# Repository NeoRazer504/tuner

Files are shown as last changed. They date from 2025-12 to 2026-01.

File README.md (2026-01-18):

# Tuner
This is a chromatic instrument tuner I made for myself because I'm a band nerd and I need a better tuner so instead of buying one, I thought it would be better to make one :). (This is my first custom project so hope it works🙏).
## Features
- Powered by a Xiao nRF52840
- Built in microphone and a jack so you can choose to use a external mic instead
- 2.42" OLED
- 3 LEDs to indicate if you're flat, sharp, or in tune
- 2 buttons to adjust hertz
- 500 mAh battery
## Gallery





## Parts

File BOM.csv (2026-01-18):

Item | Description | URL | Cost
Xiao nRF52840 | Microcontroller | https://www.digikey.com/en/products/detail/seeed-technology-co-ltd/102010448/16652893 | $9.99
3 LEDs | Pitch indicators | https://www.digikey.com/en/products/detail/american-opto-plus-led/L513SRD-C/13556881 | Already Have
3 220Ω Resistors | Resistors for LEDs | https://www.digikey.com/en/products/detail/stackpole-electronics-inc/CFM14JT220R/1742139 | Already Have
2 Buttons | Hertz controllers | https://www.digikey.com/en/products/detail/same-sky-formerly-cui-devices-/TS02-66-43-BK-100-LCR-D/15634359 | Already Have
2.42″ 2.42 inch OLED Display Module | OLED display | https://www.esp32s.com/product/2-42-2-42-inch-oled-display-module-128x64-lcd-hd-screen-module-ssd1309-7-pin-spi-iic-i2c-serial-interface-for-arduino-uno-r3 | $9.05
Adafruit I2S MEMS SPH0645LM4H | Microphone | https://www.adafruit.com/product/3421 | $6.95
Adafruit LiIon/LiPoly Backpack Add-On for Pro Trinket/ItsyBitsy | Battery charging add-on | https://www.adafruit.com/product/2124 | $4.95
Lithium Ion Polymer Battery - 3.7v 500mAh | Battery powering the tuner | https://www.digikey.com/en/products/detail/adafruit-industries-llc/1578/5054539 | $7.95
RN112BPC | 1/4 inch Jack for external microphones | https://www.digikey.com/en/products/detail/switchcraft-inc/RN112BPC/109625 | $5.67
09816 | Adapter and signal modifier for jack and microcontroller | https://www.digikey.com/en/products/detail/sparkfun-electronics/09816/5762428 | $7.25
EG1201A | Switch to turn on and off | https://www.digikey.com/en/products/detail/e-switch/EG1201A/101723 | $0.84
2 RM2X8MM 2701 | Screws for switch | https://www.digikey.com/en/products/detail/apm-hexseal/RM2X8MM-2701/612919? | $1.48
2 04M020040HN | Nuts for switch | https://www.digikey.com/en/products/detail/essentra-components/04M020040HN/9677098 | $0.30
4 6007 | Screws to attach top and bottom part of the case | https://www.digikey.com/en/products/detail/serpac/6007/307639 | $1.56
3D prints
PCB |  | https://jlcpcb.com/ | $2.00
Total cost |  |  | $67.59 + 21.37 for shipping = 79.16

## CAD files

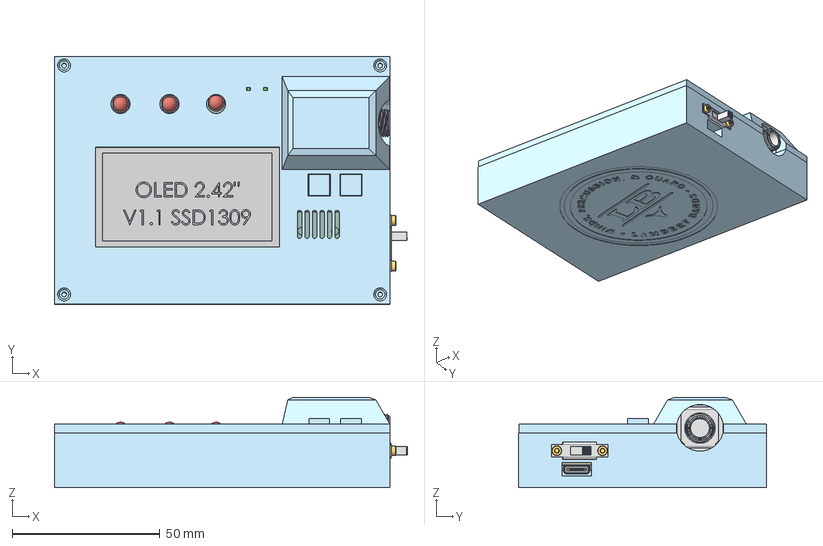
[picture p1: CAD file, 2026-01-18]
cad/assembly.step
119.5 x 84.0 x 30.6 mm
BOSS-EXTRUDE14_5_
_0805MP x 3
JSTPH2 x 5
BOSS-EXTRUDE14_7_
Silkscreen x 13
CAP x 6
0805-NO x 5
PCB (1) x 16
CHIPLED_0805_NOOUTLINE x 2
BOSS-EXTRUDE14_9_
LED x 4
500mAh battery v1
90695A025_Steel Thin Hex Nut x 2
4 PIN HEADER v2 x 2
R_Axial_DIN0207_L6.3mm_D2.5mm_P7.62mm_Horizontal x 3
BOSS-EXTRUDE14_3_
BOSS-EXTRUDE7_7_
BOSS-EXTRUDE14_4_
LED_D5.0mm x 3
CAP 3 x 3
BOSS-EXTRUDE14_10_
BOSS-EXTRUDE7_9_
Pins x 4
USR
SW_PUSH_6mm x 2
BOSS-EXTRUDE14_1_
BOSS-EXTRUDE7_5_
MIRROR2
3 PIN HEADER blk v1
Adafruit I2S Mic SPK0415HM4H_PCB
BOSS-EXTRUDE7_3_
P:\E-Switch Secure\3D_MODELS_STP_FORMAT\EG1201A.st p
BOSS-EXTRUDE7_1_
BOSS-EXTRUDE7_4_
96817A212_Thread-Forming Screws for Thin Plastic x 2
SparkFun_OpAmp_Breakout-LMV358_PCB
BOSS-EXTRUDE14_11_
XIAO-nRF52840 v15 v2
BOSS-EXTRUDE7_6_
Shield
RN112BPC
Board
BOSS-EXTRUDE14_2_
ANT1 x 3
BOSS-EXTRUDE7_2_
BOSS-EXTRUDE14_12_
SOT23-5
CUT-EXTRUDE5
6 pin header
BOSS-EXTRUDE14_6_
tuner_PCB
OLED 2.42 V1.1 SSD1309
BOSS-EXTRUDE14_8_
BOSS-EXTRUDE7_8_

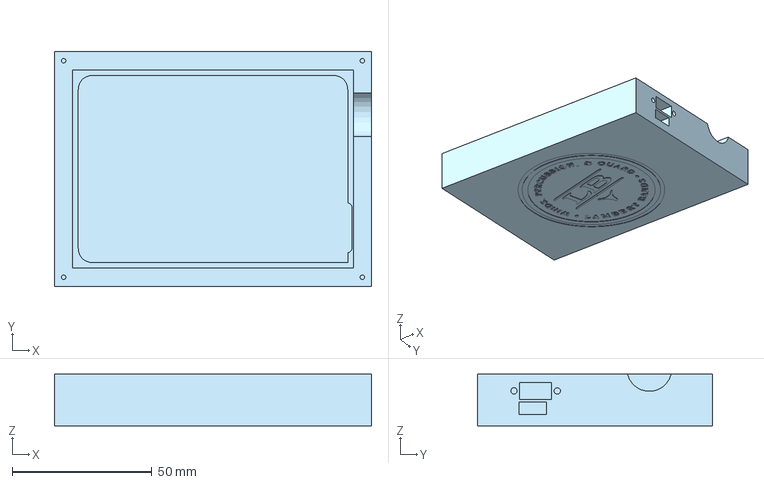
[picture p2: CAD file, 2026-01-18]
cad/Bottom Case.step
113.5 x 84.0 x 18.5 mm

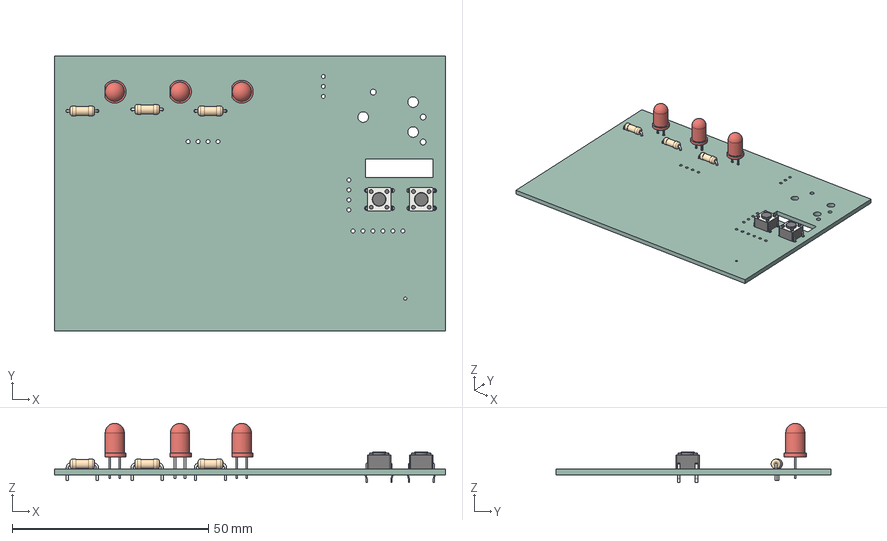
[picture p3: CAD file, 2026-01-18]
pcb/tuner.step
99.5 x 70.0 x 15.1 mm
LED_D5.0mm x 3
R_Axial_DIN0207_L6.3mm_D2.5mm_P7.62mm_Horizontal x 3
SW_PUSH_6mm x 2
tuner_PCB

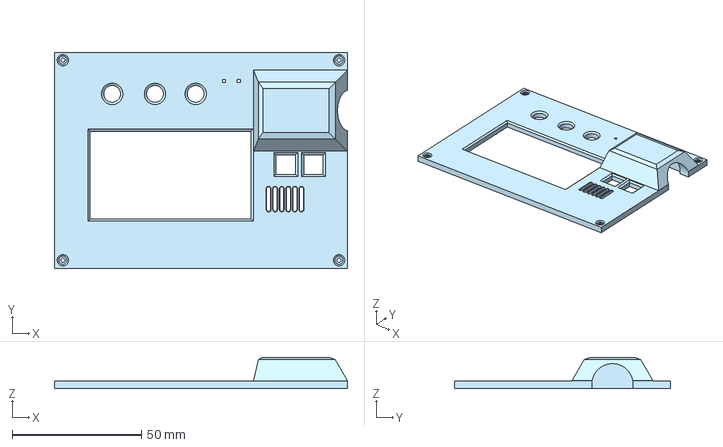
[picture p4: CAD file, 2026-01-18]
cad/Top Plate.step
113.5 x 83.8 x 12.1 mm

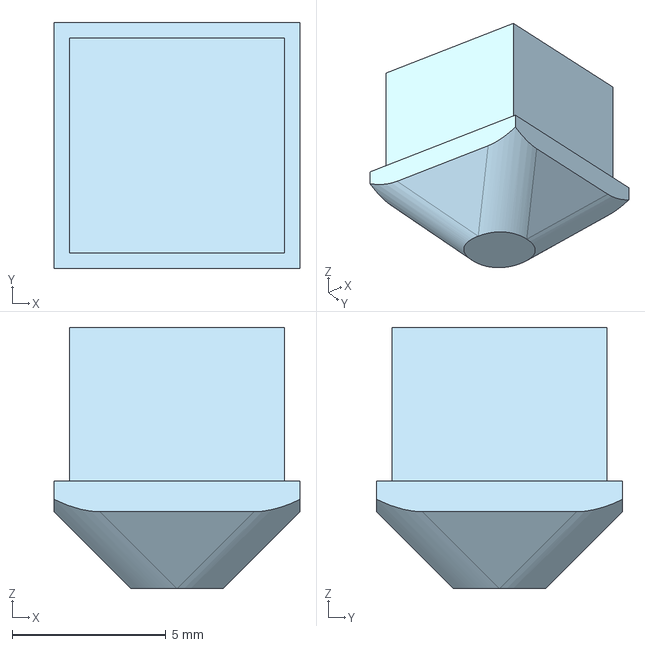
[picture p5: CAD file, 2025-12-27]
cad/Button Cap.step
8.00 x 8.00 x 8.50 mm

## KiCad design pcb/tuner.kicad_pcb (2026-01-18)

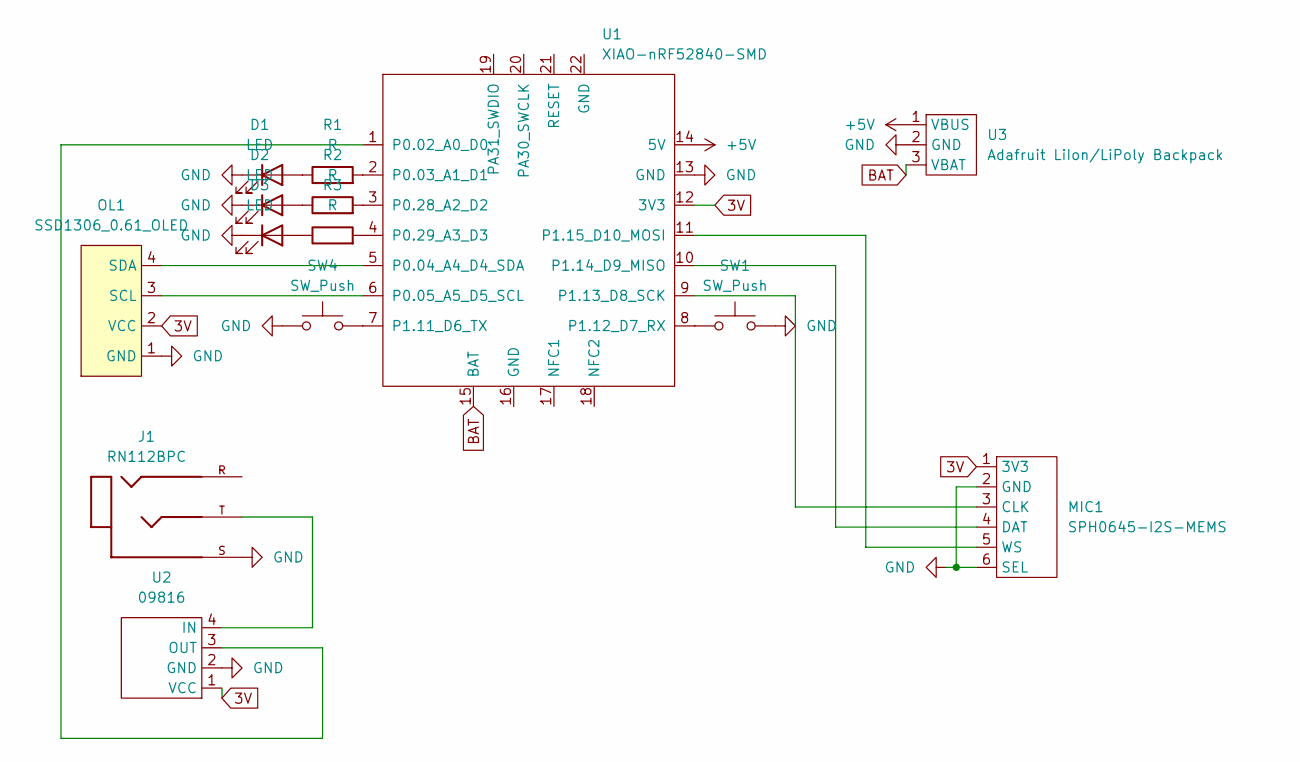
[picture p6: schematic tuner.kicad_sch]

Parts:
D1, D2, D3: LED; LED_D5.0mm
J1: RN112BPC; SWITCHCRAFT_RN112BPC; PARTREV E
MIC1: SPH0645-I2S-MEMS; Adafruit-SPH0645-I2S-MEMS-Mic
OL1: SSD1306_0.61_OLED; 2.42_ oled
R1, R2, R3: R; R_Axial_DIN0207_L6.3mm_D2.5mm_P7.62mm_Horizontal
SW1, SW4: SW_Push; SW_PUSH_6mm
U1: XIAO-nRF52840-SMD; XIAO-nRF52840-SMD-V2
U2: 09816
U3: Adafruit LiIon/LiPoly Backpack; battery backpack

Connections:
3V: MIC1.1 (3V3), OL1.2 (VCC), U1.12 (3V3), U2.1 (VCC)
+5V: U1.14 (5V), U3.1 (VBUS)
BAT: U1.15 (BAT), U3.3 (VBAT)
GND: D1.1 (K), D2.1 (K), D3.1 (K), J1.S, MIC1.2 (GND), MIC1.6 (SEL), OL1.1 (GND), SW1.2, SW4.1, U1.13 (GND), U2.2 (GND), U3.2 (GND)
unnamed: D1.2 (A), R1.1
unnamed: D2.2 (A), R2.1
unnamed: D3.2 (A), R3.1
unnamed: MIC1.3 (CLK), U1.9 (P1.13_D8_SCK)
unnamed: MIC1.4 (DAT), U1.10 (P1.14_D9_MISO)
unnamed: MIC1.5 (WS), U1.11 (P1.15_D10_MOSI)
unnamed: OL1.3 (SCL), U1.6 (P0.05_A5_D5_SCL)
unnamed: OL1.4 (SDA), U1.5 (P0.04_A4_D4_SDA)
unnamed: U1.1 (P0.02_A0_D0), U2.3 (OUT)
unnamed: R1.2, U1.2 (P0.03_A1_D1)
unnamed: R2.2, U1.3 (P0.28_A2_D2)
unnamed: R3.2, U1.4 (P0.29_A3_D3)
unnamed: SW4.2, U1.7 (P1.11_D6_TX)
unnamed: SW1.1, U1.8 (P1.12_D7_RX)
unnamed: J1.T, U2.4 (IN)

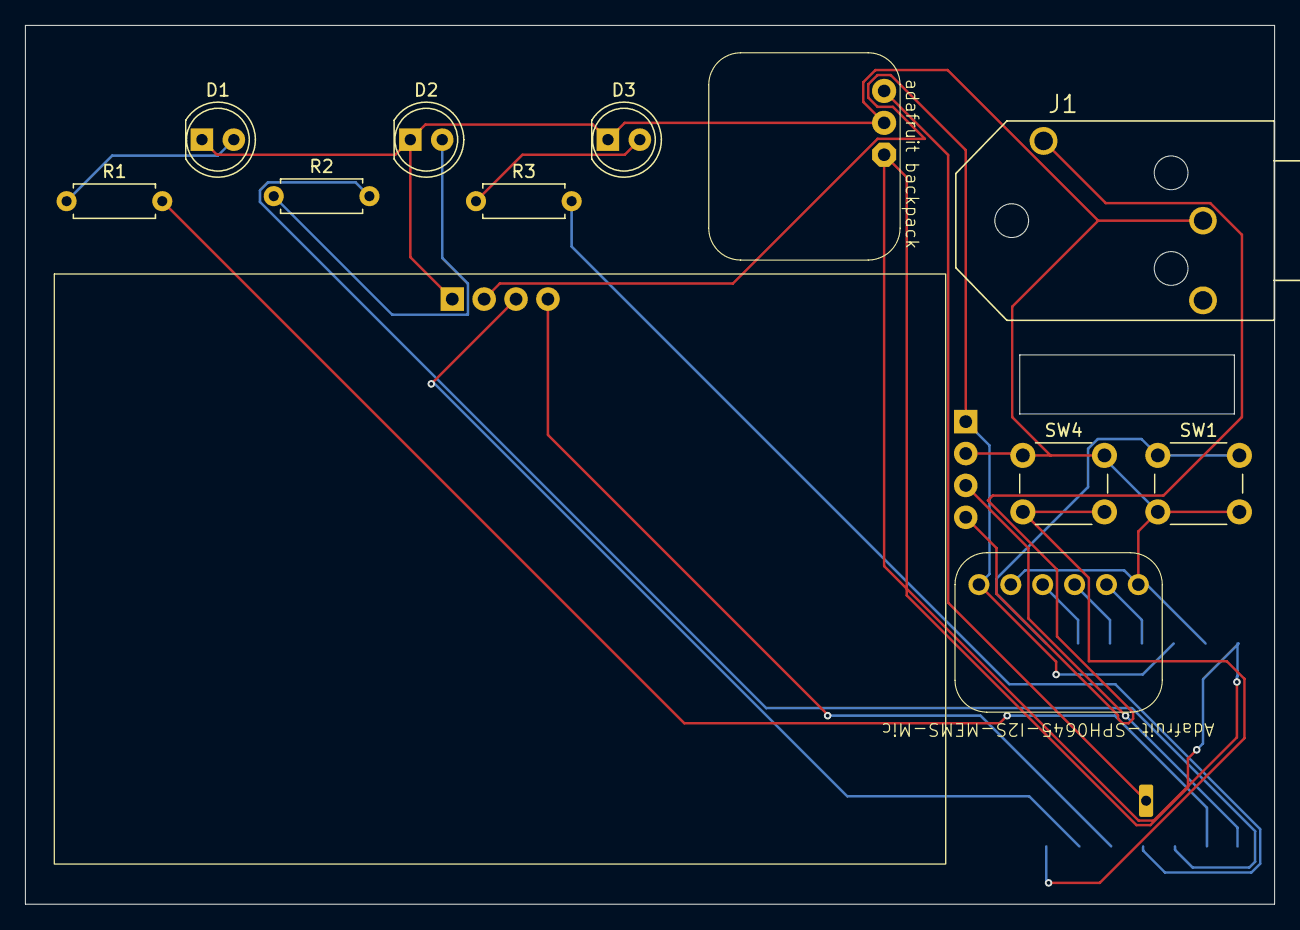
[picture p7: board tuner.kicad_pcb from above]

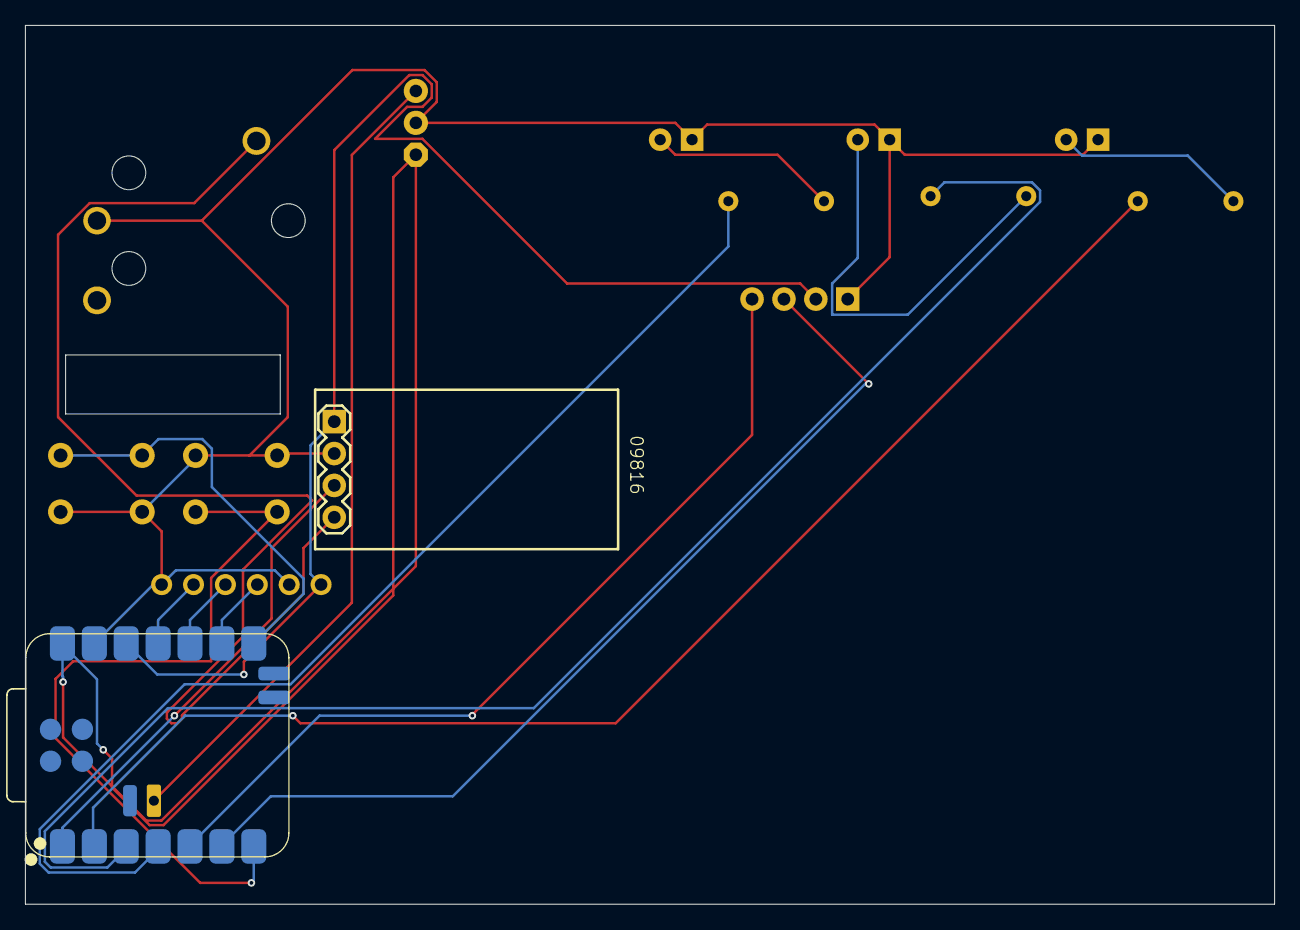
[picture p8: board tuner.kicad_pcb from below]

Board: 2 copper layers, 99.5 x 70.0 mm, 14 parts (2 on the bottom side), 19 nets.

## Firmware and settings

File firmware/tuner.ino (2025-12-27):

// Full firmware for XIAO nRF52840 tuner with button control
#include <Arduino.h>
#include <Wire.h>
#include <Adafruit_GFX.h>
#include <Adafruit_SSD1306.h>
#include <math.h>

// ========== OLED ==========
#define SCREEN_WIDTH 128
#define SCREEN_HEIGHT 64
Adafruit_SSD1306 display(SCREEN_WIDTH, SCREEN_HEIGHT, &Wire);

// ========== PINS ==========
const int AUDIO_ANALOG_PIN = A0;  // Jack input via 09B16
const int MIC_I2S_WS_PIN  = D10;
const int MIC_I2S_SD_PIN  = D9;
const int MIC_I2S_SCK_PIN = D8;

const int LED_FLAT_PIN   = D1;
const int LED_CENTER_PIN = D2;
const int LED_SHARP_PIN  = D3;

// ---- BUTTONS ----
const int BTN_UP_PIN   = D6;  // increase Hz
const int BTN_DOWN_PIN = D7;  // decrease Hz

// ========== CONFIG ==========
float targetFrequency = 440.0f;  // now variable, not constant
const float CENTER_TOLERANCE_CENTS = 5.0f;
const float ANALOG_SAMPLE_RATE = 8000.0f;
const float I2S_SAMPLE_RATE    = 16000.0f;
const int   BUFFER_SIZE        = 512;
const int JACK_ACTIVITY_THRESHOLD = 20;

enum class AudioSource { JackAnalog, I2SMic };

// ========== BUTTON HANDLING ==========
bool readButton(int pin) {
  return digitalRead(pin) == LOW;  // assuming buttons pull to GND
}

void handleButtons() {
  static unsigned long lastPress = 0;
  unsigned long now = millis();

  if (now - lastPress < 150) return;  // debounce

  if (readButton(BTN_UP_PIN)) {
    targetFrequency += 1.0f;
    lastPress = now;
  }

  if (readButton(BTN_DOWN_PIN)) {
    targetFrequency -= 1.0f;
    if (targetFrequency < 1) targetFrequency = 1;  // prevent negative/zero
    lastPress = now;
  }
}

// ========== SETUP ==========
void setup() {
  Serial.begin(115200);
  delay(500);
  display.begin(SSD1306_SWITCHCAPVCC, 0x3C);
  display.clearDisplay();
  display.display();

  pinMode(LED_FLAT_PIN,   OUTPUT);
  pinMode(LED_CENTER_PIN, OUTPUT);
  pinMode(LED_SHARP_PIN,  OUTPUT);
  pinMode(AUDIO_ANALOG_PIN, INPUT);

  // Buttons
  pinMode(BTN_UP_PIN,   INPUT_PULLUP);
  pinMode(BTN_DOWN_PIN, INPUT_PULLUP);

  display.setTextSize(2);
  display.setTextColor(SSD1306_WHITE);
  display.setCursor(0, 0);
  display.println("Tuner");
  display.setTextSize(1);
  display.println("XIAO nRF52840");
  display.display();
  delay(1000);
}

// ========== MAIN LOOP ==========
void loop() {
  handleButtons();  // <-- NEW

  static int16_t buffer[BUFFER_SIZE];
  AudioSource source = selectAudioSource();

  bool ok = false;
  if (source == AudioSource::JackAnalog) {
    ok = captureAnalogBuffer(buffer, BUFFER_SIZE);
  } else {
    ok = captureI2SBuffer(buffer, BUFFER_SIZE);
  }

  if (!ok) {
    showError("Audio capture fail");
    delay(100);
    return;
  }

  float sampleRate = (source == AudioSource::JackAnalog) ? ANALOG_SAMPLE_RATE : I2S_SAMPLE_RATE;
  float freq = estimateFrequency(buffer, BUFFER_SIZE, sampleRate);
  float cents = computeCentsDifference(freq, targetFrequency);

  updateTuningLeds(cents);
  updateTunerDisplay(freq, cents, source);
  delay(20);
}

// ========== AUDIO ==========
AudioSource selectAudioSource() {
  long sumAbs = 0;
  for (int i = 0; i < 64; ++i) {
    int raw = analogRead(AUDIO_ANALOG_PIN);
    sumAbs += abs(raw - 2048);
    delayMicroseconds(100);
  }
  return (sumAbs / 64 > JACK_ACTIVITY_THRESHOLD) ? AudioSource::JackAnalog : AudioSource::I2SMic;
}

bool captureAnalogBuffer(int16_t* buffer, int length) {
  unsigned long period = 1000000.0f / ANALOG_SAMPLE_RATE;
  unsigned long next = micros();
  for (int i = 0; i < length; ++i) {
    while ((long)(micros() - next) < 0);
    buffer[i] = analogRead(AUDIO_ANALOG_PIN) - 2048;
    next += period;
  }
  return true;
}

bool captureI2SBuffer(int16_t* buffer, int length) {
  // TODO: Replace with actual I2S mic capture code once Seeed exposes API
  return false;
}

// ========== TUNER ==========
float estimateFrequency(const int16_t* buffer, int length, float sampleRate) {
  int zeroCrossings = 0;
  for (int i = 1; i < length; ++i) {
    if ((buffer[i - 1] < 0 && buffer[i] >= 0) || (buffer[i - 1] > 0 && buffer[i] <= 0)) {
      zeroCrossings++;
    }
  }
  float cycles = zeroCrossings / 2.0f;
  float duration = length / sampleRate;
  return (duration > 0.0f && cycles > 0.0f) ? cycles / duration : 0.0f;
}

float computeCentsDifference(float measuredFreq, float targetFreq) {
  return (measuredFreq > 0.0f && targetFreq > 0.0f)
    ? 1200.0f * log(measuredFreq / targetFreq) / log(2.0f)
    : 0.0f;
}

// ========== LED ==========
void updateTuningLeds(float cents) {
  digitalWrite(LED_FLAT_PIN,   cents < -CENTER_TOLERANCE_CENTS);
  digitalWrite(LED_CENTER_PIN, abs(cents) <= CENTER_TOLERANCE_CENTS);
  digitalWrite(LED_SHARP_PIN,  cents > CENTER_TOLERANCE_CENTS);
}

// ========== DISPLAY ==========
void showError(const char* msg) {
  display.clearDisplay();
  display.setTextSize(1);
  display.setCursor(0, 0);
  display.println("Error:");
  display.println(msg);
  display.display();
}

void updateTunerDisplay(float freq, float cents, AudioSource src) {
  display.clearDisplay();
  display.setTextSize(1);
  display.setCursor(0, 0);

  display.print("Src: ");
  display.println((src == AudioSource::JackAnalog) ? "Jack" : "Mic");

  display.print("Freq: ");
  display.print(freq, 1);
  display.println(" Hz");

  display.print("Target: ");
  display.print(targetFrequency, 1);
  display.println(" Hz");

  display.print("Cents: ");
  display.print(cents, 1);

  int centerX = SCREEN_WIDTH / 2;
  int centerY = 40;
  int barLength = 40;
  float maxCents = 50.0f;
  float norm = constrain(cents / maxCents, -1.0f, 1.0f);
  int barX = centerX + (int)(norm * (barLength / 2));

  display.drawLine(centerX, centerY - 5, centerX, centerY + 5, SSD1306_WHITE);
  display.drawLine(barX, centerY - 8, barX, centerY + 8, SSD1306_WHITE);
  display.display();
}

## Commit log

2025-12-27 Update and rename tuner.kicad_pcb to pcb/tuner.kicad_pcb
    [tuner.kicad_pcb]
2025-12-27 Update and rename tuner.kicad_sch to pcb/tuner.kicad_sch
    [tuner.kicad_sch]
2025-12-28 Rename tuner 1.step to assembly.step
    [assembly.step]
2025-12-28 Add 500 mAh battery specification
    Add battery specification to product features
2025-12-28 Add BOM.csv with XIAO nRF52840 details
    [BOM.csv]
2025-12-28 Add components and costs to BOM.csv
    [BOM.csv]
2025-12-28 Correct formatting of 1/4 inch Jack description
    [BOM.csv]
2025-12-28 Change URL for Xiao nRF52840 in BOM.csv
    Updated the URL for the Xiao nRF52840 microcontroller.
    [BOM.csv]
2025-12-28 Revise BOM with new component details and costs
    Updated BOM.csv with new URLs and costs for components.
    [BOM.csv]
2026-01-18 Update BOM.csv with new PCB cost and total cost
    [BOM.csv]
